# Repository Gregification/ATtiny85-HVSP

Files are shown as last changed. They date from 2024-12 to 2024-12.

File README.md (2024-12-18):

### ATtiny85 HVSP for reset-locked device recovery (hand solderable)

> this hardware can be used on some chips of the same family after slight modification.

uses one ATTiny85 to recover other reset-locked ATtiny85's. Done by bringing the target ATtiny85 into HVSP mode, to reprogram the high fuse bits to `0xDF`.

[schematic view pdf](./demo/top%20level.pdf)

### Details
- Kicad 8.0
- master ATTiny85 operates at 8MHz(optional) with reset pin set to act as GPIO(required).
- made from common components. notable exceptions listed.
    - the [MIC2290](https://ww1.microchip.com/downloads/en/DeviceDoc/MIC2290.pdf) (boost converter IC to supply 12V; ~$1.00 for a order of 1 from Digikey), **this can be substituted** with a 12V supply tapped to the same trace.
    - the USB connector **can be substituted** with a 5V supply tapped to the same trace.

---

| Count | Component |
|-|-|
| 1 | MIC2290 boost converter IC |
| 1 | USB A plug |
| 1 | single pole switch (optional) |
| 1 | ATtiny85 |
| 1 | 44.2k Ohm |
| 5 | 5k Ohm |
| 4 | 1.2k ohm
| 1 | 10uH |
| 1 | 100nF |
| 2 | 10uF |
| 1 | diode (optional) |
| 2 | NPN BJT |
| 2 | PNP BJT |

---

<div style="display:flex; align-items:top;">
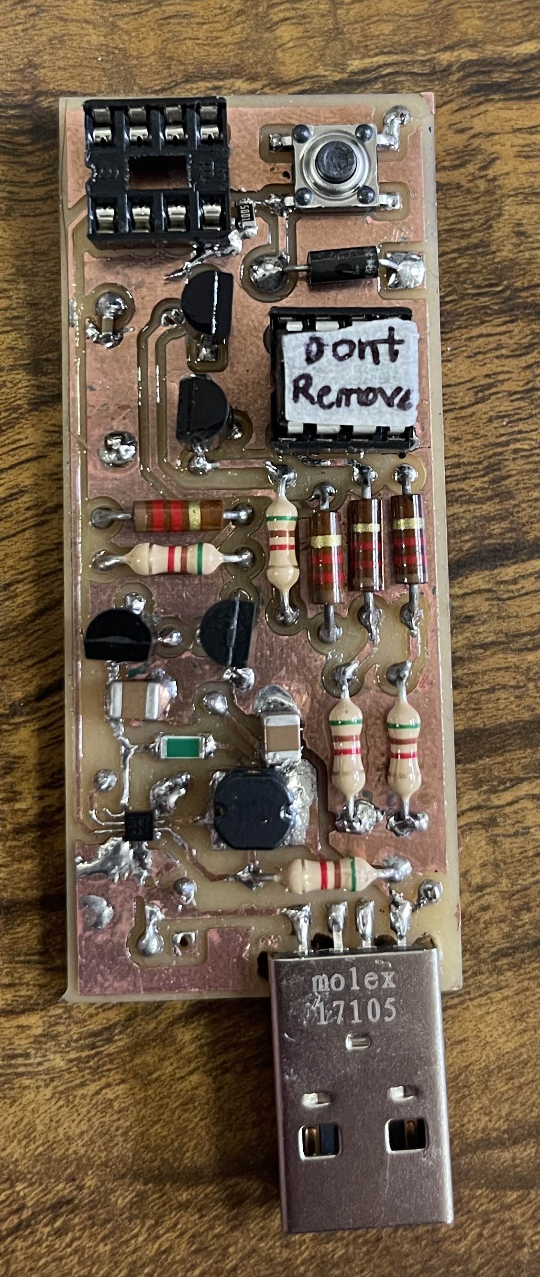
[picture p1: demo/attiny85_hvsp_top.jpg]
board top
  
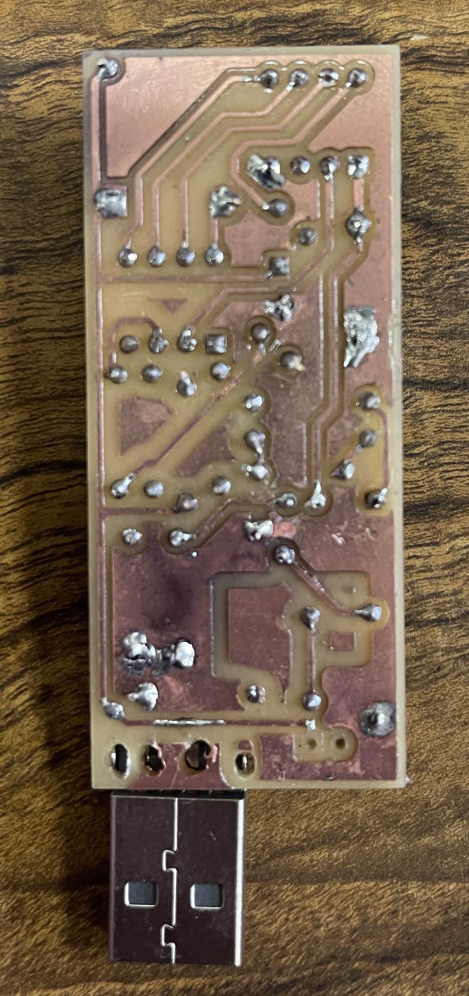
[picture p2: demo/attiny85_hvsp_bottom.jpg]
board bottom
    
</div>

<p style="text-indent:1rem;">As shown, empty DIP socket holds target; master has a "dont remove" sticker. 100nF disk has been subsuited with a same sized SMD. 20k ohm pull down added on the buttons low side because the exact button used acts as a ~2M ohm resistor in its off state. Extra solder points because my maufacturing does not support plated vias, manually 'plating' was needed.</p>

---
<div style="display:flex; align-items:top;">
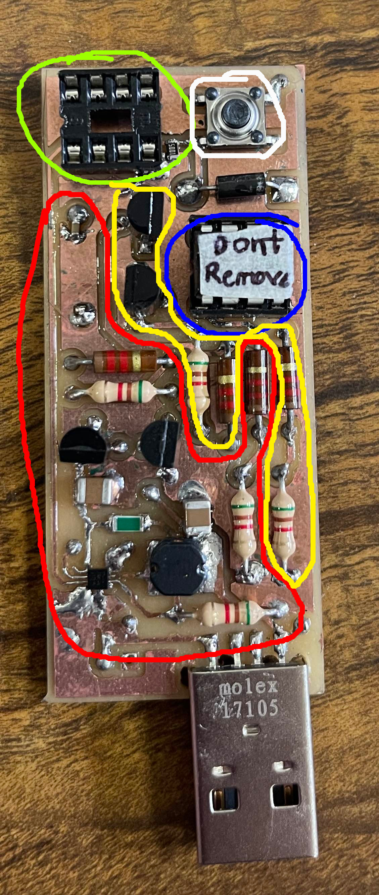
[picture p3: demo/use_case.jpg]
board top with circuit sections outlined
    
    <div style="margin-left:.5rem;" width="49%">
        <h3>Coloring</h3>
        <ul>
            <li>Green: reset-locked chip goes here</li>
            <li>White: go button</li>
            <li>Blue: master chip goes here</li>
            <li>red: 12V control circuitry</li>
            <li>yellow: 5V control circuitry</li>
        </ul>
        <h3>Setup</h3>
        <ol>
            <li>fab & assemble board</li>
            <li>program a master ATtiny85 using the code from the 'code' sub folder of this project. note that master ATtiny85 uses its reset pin as GPIO so the approate fuse bit needs set.</li>
            <li>put master in the blue outlined socket; notch to the left.</li>
        </ol>
        <h3>Operation</h3>
        <ol>
            <li>put reset-locked ATtiny85 in the green indicated socket; notch to the left.</li>
            <li>press & hold button for ~0.5 seconds</li>
            <li>target chip is now unbricked!</li>
        </ol>
    </div>
</div>

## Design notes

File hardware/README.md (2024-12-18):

- designed for hand soldering
- footprint choices influenced by what I had on hand

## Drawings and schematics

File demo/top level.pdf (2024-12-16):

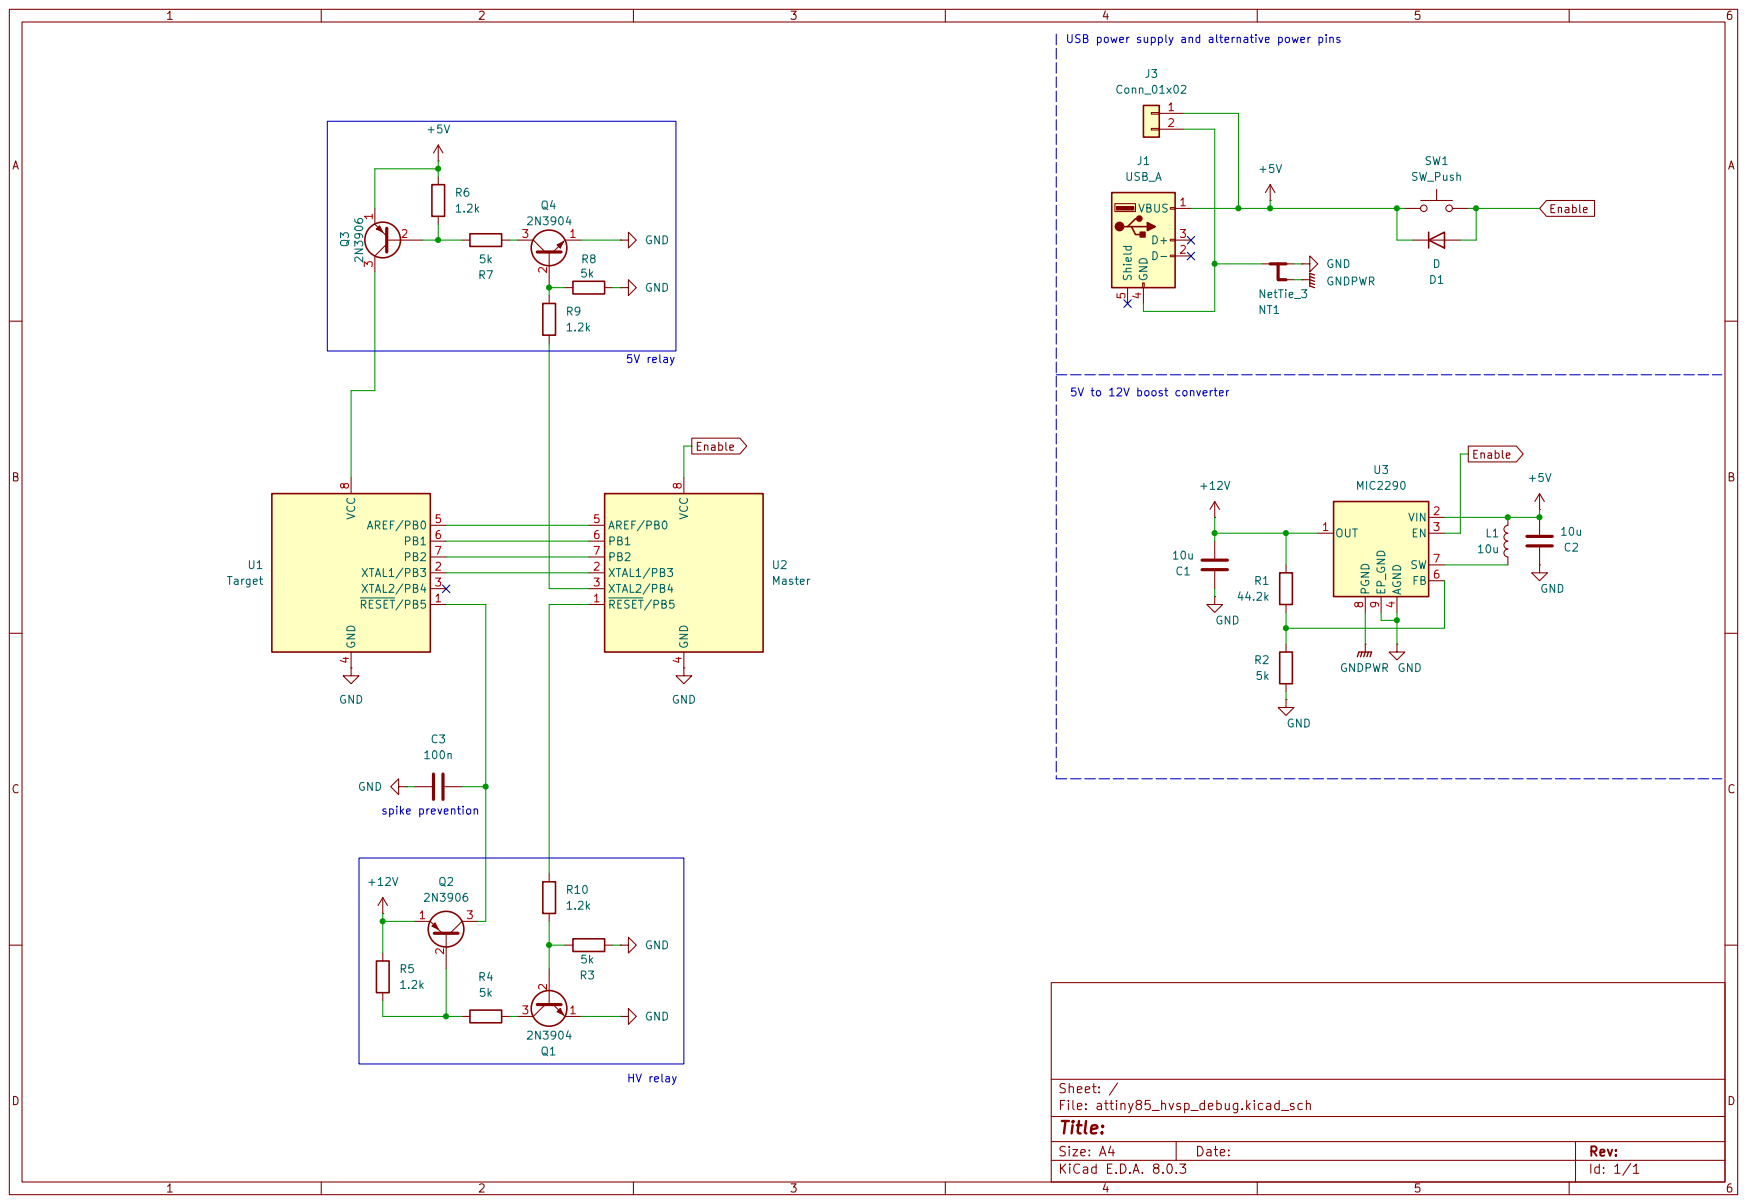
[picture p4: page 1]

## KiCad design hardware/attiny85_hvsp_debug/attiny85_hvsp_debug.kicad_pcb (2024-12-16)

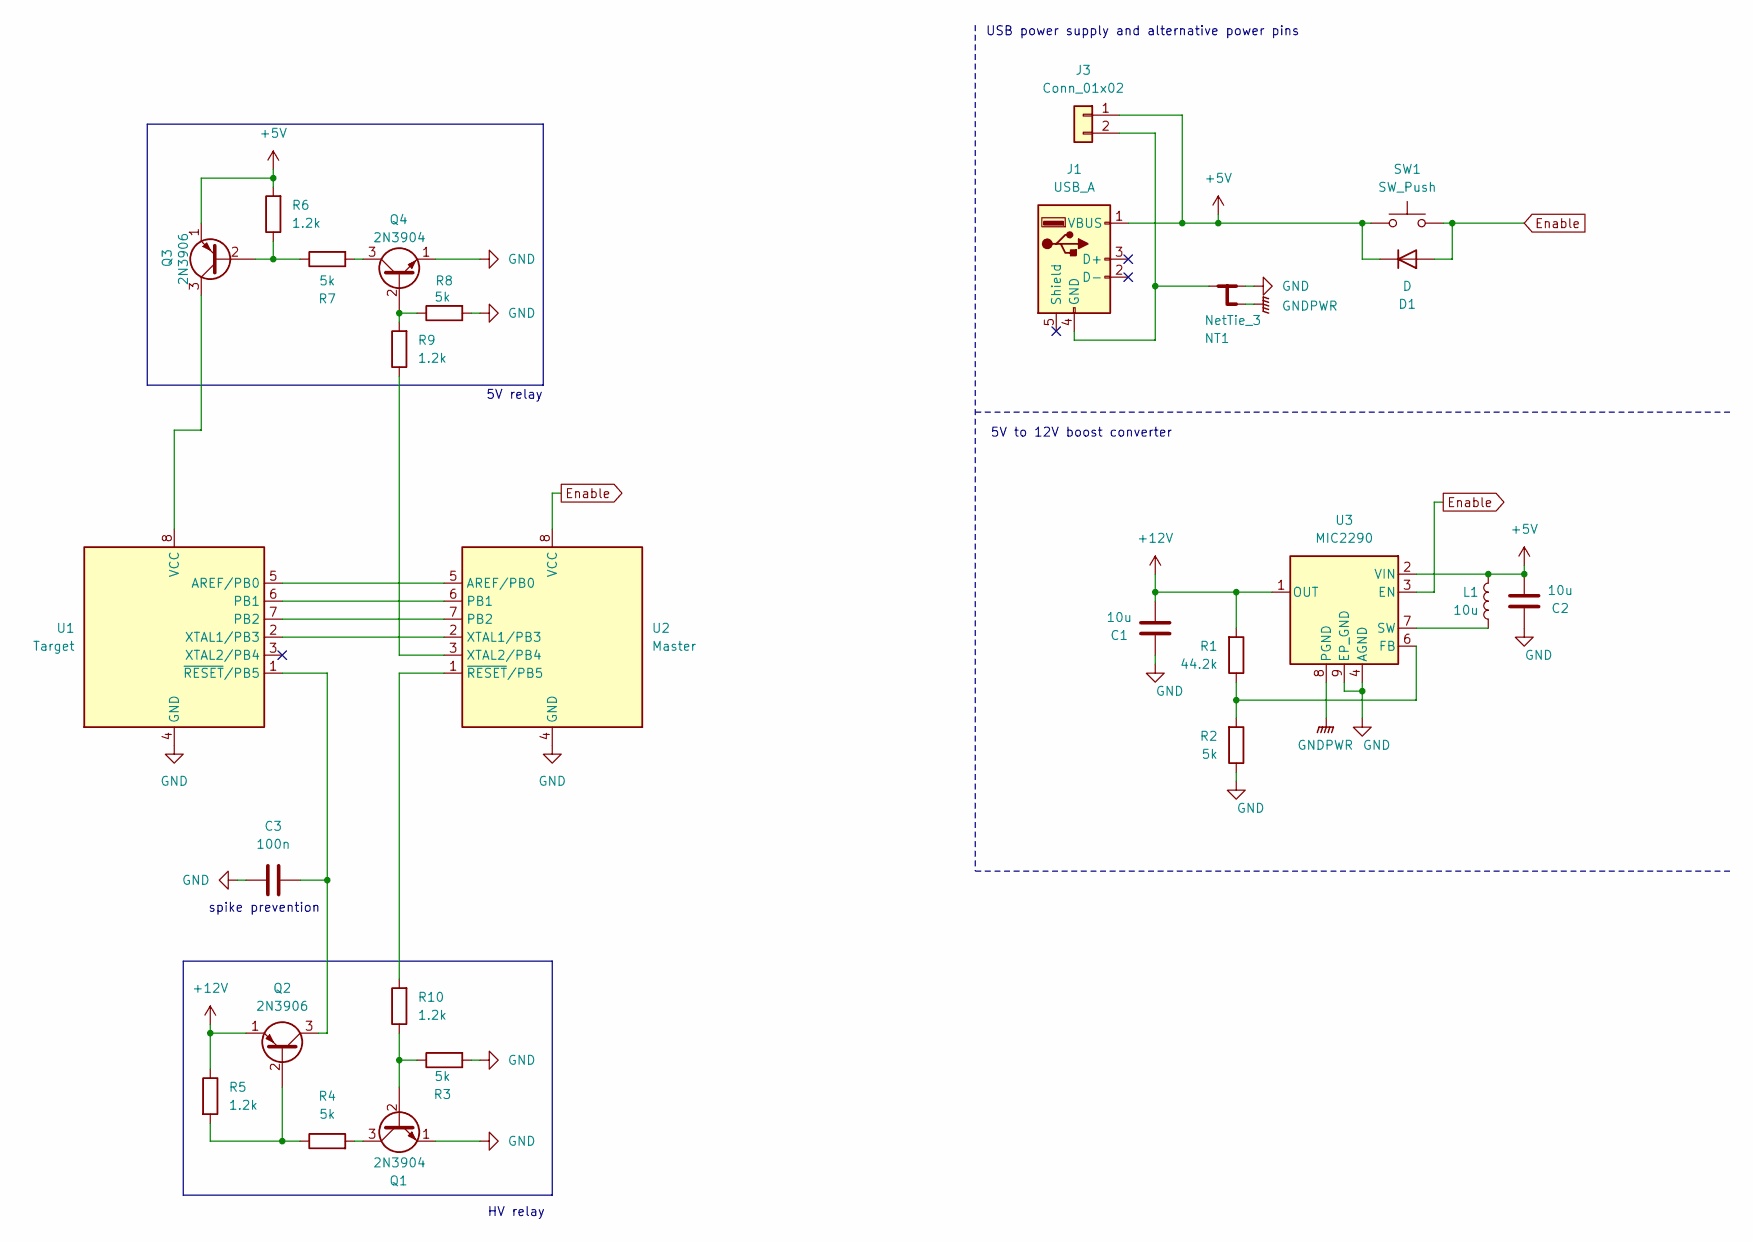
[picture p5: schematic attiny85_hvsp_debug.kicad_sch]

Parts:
C1, C2: 10u; C_1210_3225Metric
C3: 100n; C_Disc_D16.0mm_W5.0mm_P10.00mm
D1: D; D_5W_P10.16mm_Horizontal
J1: USB_A; USB_A_Molex_48037-2200_Horizontal
J3: Conn_01x02; PinHeader_1x02_P2.54mm_Vertical
L1: 10u; IDCP2218-01
NT1: NetTie_3; NetTie-3_SMD_Pad0.5mm
Q1, Q4: 2N3904; TO-92L_Wide
Q2, Q3: 2N3906; TO-92L_Wide
R1: 44.2k; R_1206_3216Metric
R2, R3, R4, R7, R8: 5k; R_Axial_DIN0207_L6.3mm_D2.5mm_P10.16mm_Horizontal
R5, R6, R9, R10: 1.2k; R_Axial_DIN0207_L6.3mm_D2.5mm_P10.16mm_Horizontal
SW1: SW_Push; SW_SPST_Omron_B3FS-101xP
U1: Target; DIP-8_W7.62mm
U2: Master; DIP-8_W7.62mm
U3: MIC2290; Micrel_MLF-8-1EP_2x2mm_P0.5mm_EP0.6x1.2mm

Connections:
+5V: C2.1, D1.1 (K), J1.1 (VBUS), J3.1, L1.1, Q3.1 (E), R6.2, SW1.1, U3.2 (VIN)
+12V: C1.1, Q2.1 (E), R1.2, R5.1, U3.1 (OUT)
Enable: D1.2 (A), SW1.2, U2.8 (VCC), U3.3 (EN)
GND: C1.2, C2.2, C3.1, NT1.1, Q1.1 (E), Q4.1 (E), R2.1, R3.2, R8.2, U1.4 (GND), U2.4 (GND), U3.4 (AGND), U3.9 (EP_GND)
GNDPWR: NT1.3, U3.8 (PGND)
unnamed: J1.4 (GND), J3.2, NT1.2
unnamed: Q1.2 (B), R3.1, R10.1
unnamed: Q1.3 (C), R4.2
unnamed: Q2.2 (B), R4.1, R5.2
unnamed: C3.2, Q2.3 (C), U1.1 (~RESET/PB5)
unnamed: Q3.2 (B), R6.1, R7.1
unnamed: Q3.3 (C), U1.8 (VCC)
unnamed: Q4.2 (B), R8.1, R9.2
unnamed: Q4.3 (C), R7.2
unnamed: U1.5 (AREF/PB0), U2.5 (AREF/PB0)
unnamed: U1.6 (PB1), U2.6 (PB1)
unnamed: U1.7 (PB2), U2.7 (PB2)
unnamed: U1.2 (XTAL1/PB3), U2.2 (XTAL1/PB3)
unnamed: R9.1, U2.3 (XTAL2/PB4)
unnamed: R10.2, U2.1 (~RESET/PB5)
unnamed: R1.1, R2.2, U3.6 (FB)
unnamed: L1.2, U3.7 (SW)

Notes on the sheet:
5V relay
HV relay
spike prevention
USB power supply and alternative power pins
5V to 12V boost converter

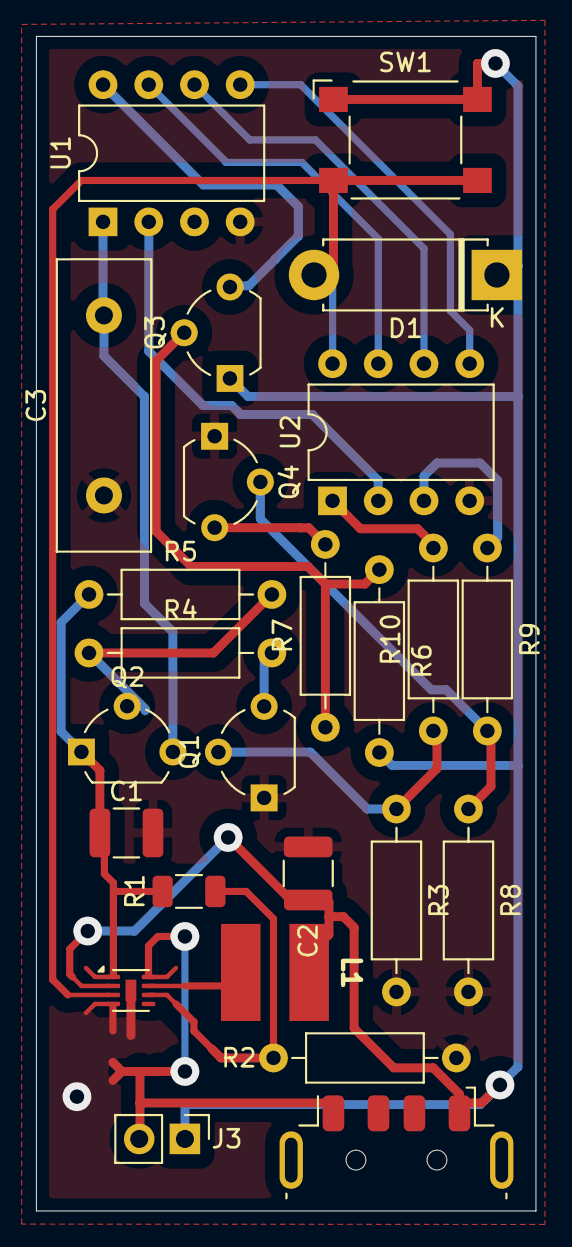
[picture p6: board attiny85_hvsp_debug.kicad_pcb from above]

Board: 2 copper layers, 27.8 x 65.2 mm, 26 parts (0 on the bottom side), 22 nets.

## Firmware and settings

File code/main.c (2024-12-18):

/**
 * ATtiny85 HVSP reset lock recovery
 *  code for master ATtiny85
 * 
 *  WARNING: ONLY TO BE USED AGAINST OTHER ATtiny85's
 * 
 * writes the fueses
 *  H   0xDF
 * 
 * note:
 *  - code is pov of the master, but datasheet is slave pov
 *  - master runs at 8 MHz
 *  - master has Reset pin as GPIO
 */

#ifndef __AVR_ATtiny85__
#define __AVR_ATtiny85__
#endif

#ifndef F_CPU
#define F_CPU 8000000UL
#endif

#define CLK_DELAY_us    3   

#include <stdbool.h>
#include <stdint.h>
#include <avr/io.h>
#include <util/delay.h>

// uP chapter 20.6
#define SDI             _BV(PB0)
#define SII             _BV(PB1)
#define SDO             _BV(PB2)
#define SCI             _BV(PB3)
#define VCC_CTRL        _BV(PB4)
#define HV_CTRL         _BV(PB5)
#define PROG_ENABLE0    SDI
#define PROG_ENABLE1    SII
#define PROG_ENABLE2    SDO

typedef struct {
    uint8_t input;
    uint8_t instruction;
    uint8_t output;
} Instr;
void transfer_instruction(Instr* txrx, uint8_t len);

int main(){
    //------------------------------------------------------------------------------------
    //  WARNING: ONLY TO BE USED AGAINST OTHER ATtiny85's
    //------------------------------------------------------------------------------------
    
    //------------------------------------------------------------------------------------
    //  init
    //------------------------------------------------------------------------------------

    DDRB |= SCI | SII | SDI | SDO | HV_CTRL | VCC_CTRL; // outputs

    // everything to low
    PORTB &= ~(SCI | SII | SDI | SDO | HV_CTRL | VCC_CTRL);

    //------------------------------------------------------------------------------------
    // enter HVSP mode - uP chapter 20.7.1
    //------------------------------------------------------------------------------------

    // 1. Set Prog_enable pins listed in Table 20-14 to “000”, RESET pin and VCC to 0V.
    PORTB &= ~(PROG_ENABLE0 | PROG_ENABLE1 | PROG_ENABLE2 | HV_CTRL | VCC_CTRL);

    _delay_ms(100); // wait for latches

    // 2. Apply 4.5 - 5.5V between VCC and GND. Ensure that VCC reaches at least 1.8V within the next 20 μs.
    PORTB |= VCC_CTRL;

    // 3. Wait 20 - 60 μs, and apply 11.5 - 12.5V to RESET.
    _delay_us(30);
    PORTB |= HV_CTRL;

    // 4. Keep the Prog_enable pins unchanged for at least 10 μs after the High-voltage has been applied to
    //      ensure the Prog_enable Signature has been latched.
    _delay_us(15);

    // 5. Release the Prog_enable[2] pin to avoid drive contention on the Prog_enable[2]/SDO pin.
    
    // set PROG_ENABLE2 to Hi-Z input
    DDRB    &= ~PROG_ENABLE2;         // set as input
    PORTB   &= ~PROG_ENABLE2;         // disable bias resistors

    // 6. Wait at least 300 μs before giving any serial instructions on SDI/SII.
    _delay_us(350);


    //------------------------------------------------------------------------------------
    // program high fuses
    //------------------------------------------------------------------------------------
    {
        Instr *instrs;
        
        // set fuse bits to 0xDF
        instrs = (Instr[4]){
                  {0x40  ,   0x4C},
                  {0xDF  ,   0x2C},
                  {0x00  ,   0x74},
                  {0x00  ,   0x7C},
                };
        transfer_instruction(instrs, 4);
    }

    //------------------------------------------------------------------------------------
    // exit
    //------------------------------------------------------------------------------------
    
    PORTB &= ~(VCC_CTRL | HV_CTRL);

    while(true)
        ;

    return 0;
}

void transfer_instruction(Instr* txrx, uint8_t len){
    if(!txrx)
        return;

    /* basically just 11 bit SPI with the following gimics
     *  - 2 parallel data lines, SDI and SII
     *  - SDI, SII, and SDO are 8 bit values, MSB first, left aligned within the 11 bits
     *  - SDI and SII uses SPI mode 1
     *  - SDO uses SPI mode 0
     *  - 0's are used as padding bits
     */

    PORTB &= ~SCI; // ensure clock is low (it should already be low)

    uint8_t packet_i;
    for(packet_i = 0; packet_i < len; packet_i++){
        
        // this delay is not necesasry but makes waveform easier to read
        _delay_us(CLK_DELAY_us);

        uint8_t bit_i;
        for(bit_i = 0; bit_i < 11; bit_i++){

            _delay_us(CLK_DELAY_us);
            PORTB |= SCI;

            _delay_us(CLK_DELAY_us);
            PORTB &= ~SCI;

            // SDO
            txrx[packet_i].output |= ((PINB | SDO) != 0) << (7-bit_i);

            // SDI
            if((txrx[packet_i].input       >> (7-bit_i)) & 1)
                PORTB |= SDI;
            else
                PORTB &= ~SDI;

            // SII
            if((txrx[packet_i].instruction >> (7-bit_i)) & 1)
                PORTB |= SII;
            else
                PORTB &= ~SII;

        }
    }
}

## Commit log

2024-12-04 brought over from homelab repo
    [attiny85_hvsp.kicad_pcb, attiny85_hvsp.kicad_sch]
2024-12-16 brute forced BJT design
    [attiny85_hvsp_debug.kicad_pcb, attiny85_hvsp_debug.kicad_sch]
2024-12-18 updated readme & tidied up project
    [attiny85_hvsp.kicad_pcb, attiny85_hvsp.kicad_sch]
